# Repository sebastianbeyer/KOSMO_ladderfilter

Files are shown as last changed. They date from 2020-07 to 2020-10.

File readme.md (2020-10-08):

A Kosmo version of the [Kassutronics transistor ladder filter](https://kassu2000.blogspot.com/2018/07/transistor-ladder-filter.html).

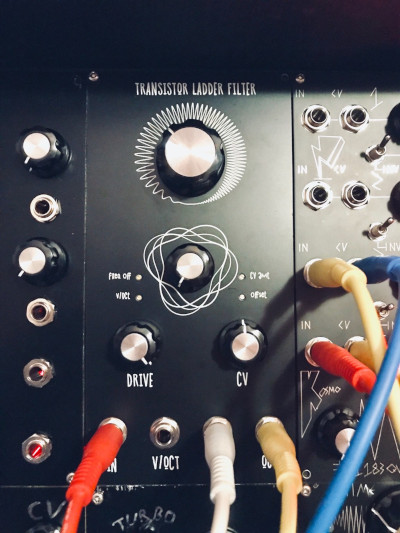
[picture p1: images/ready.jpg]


Find the documentation **and BOM** here: (https://github.com/kassu/kassutronics/tree/master/documentation/Transistor%20Ladder%20Filter)

You need to match the transistors, which is a bit boring. Those that I got where
already pretty close (within the recommended 2mV limit), but some outliers, so
maaaybe you could just try without matching.

# How to make the PCBs

Go download the latest gerber files [here](https://github.com/sebastianbeyer/KOSMO_ladderfilter/releases/latest).
Then send them to your favorite PCB Manufacturer (I use jlcpcb). Make sure you
check "Specify a location" at "Remove Order Number" for the panel.

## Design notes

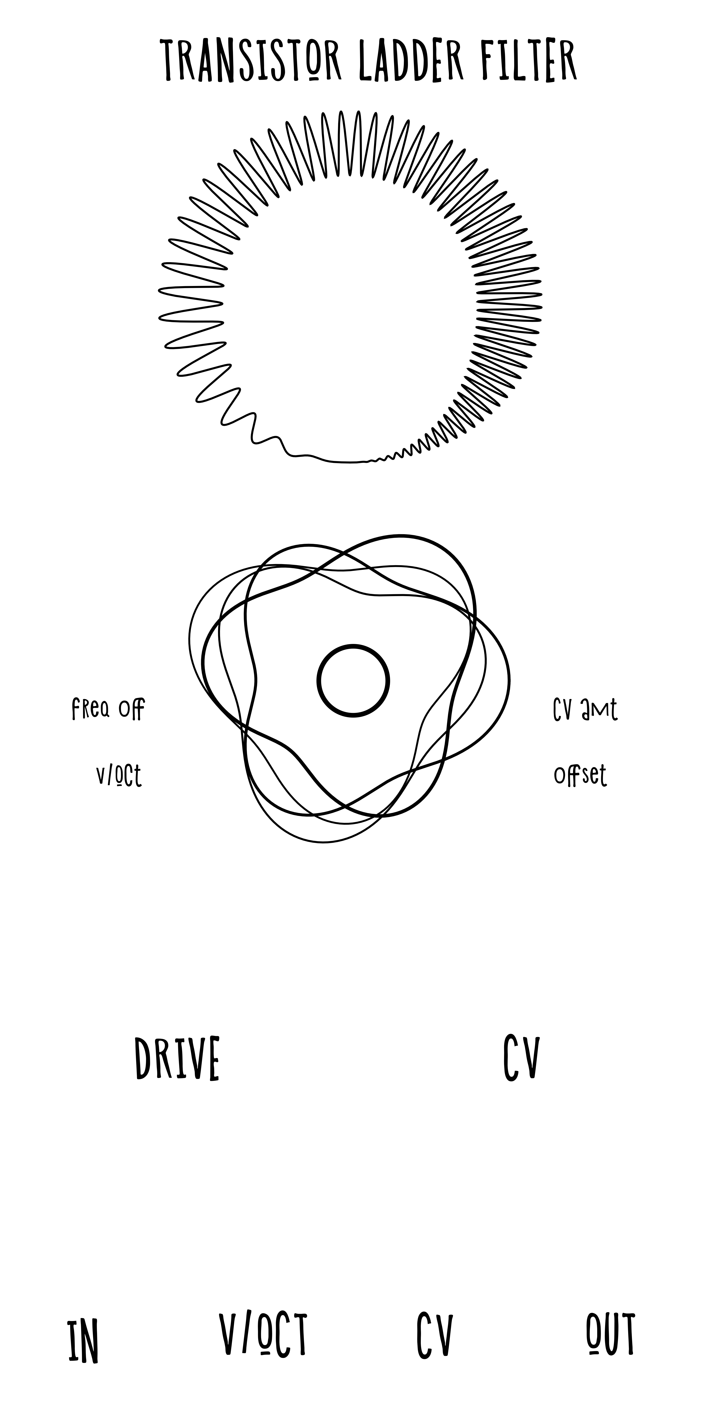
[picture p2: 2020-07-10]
panel/svg/panel_silkscreen.png

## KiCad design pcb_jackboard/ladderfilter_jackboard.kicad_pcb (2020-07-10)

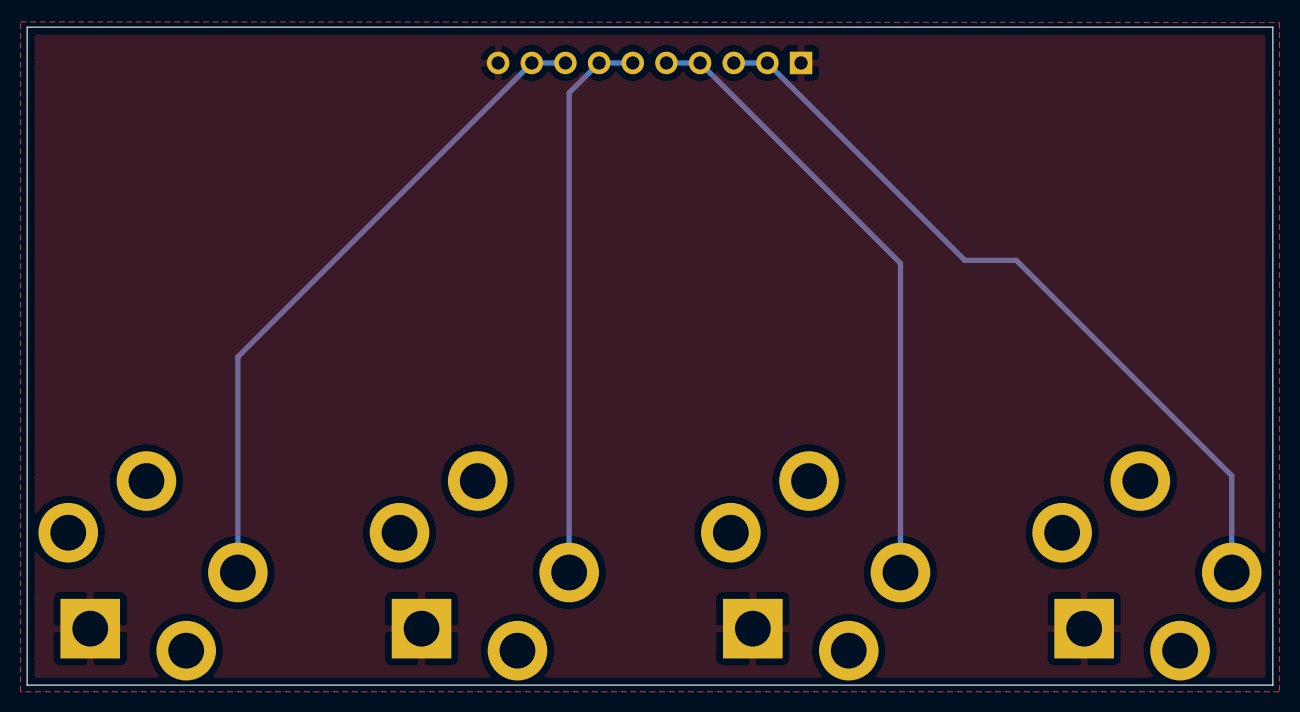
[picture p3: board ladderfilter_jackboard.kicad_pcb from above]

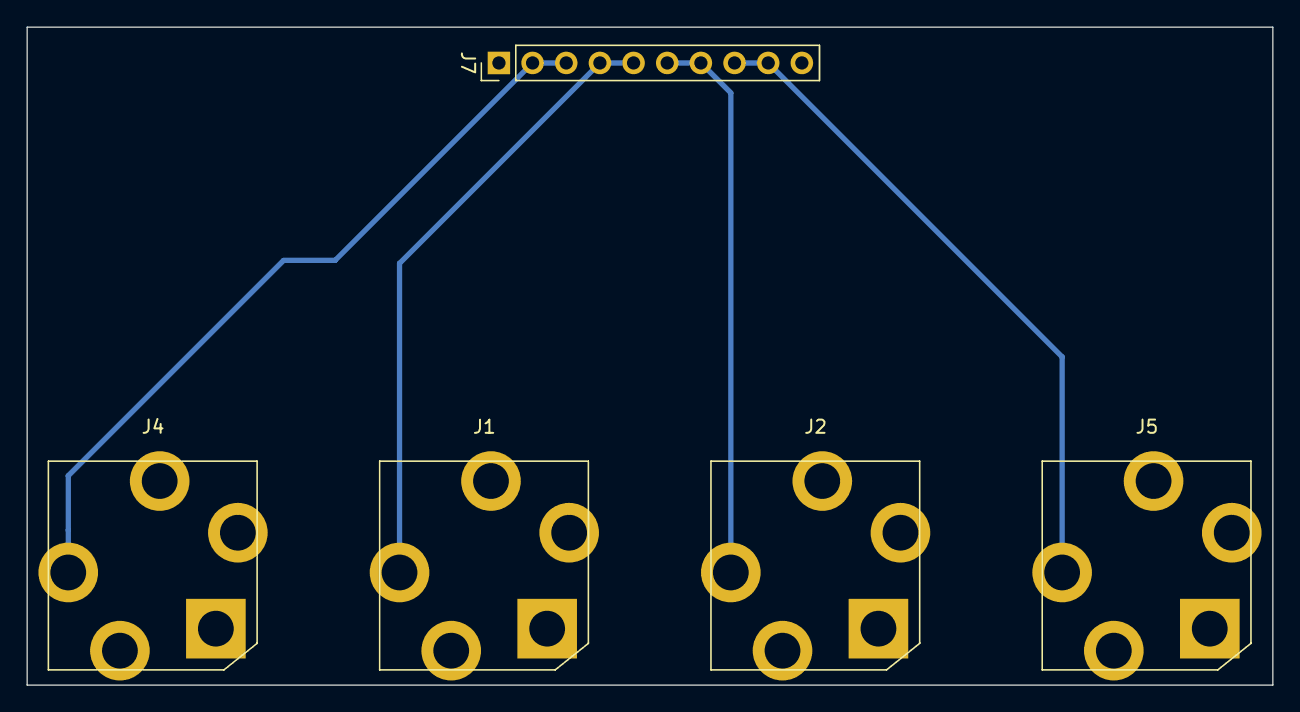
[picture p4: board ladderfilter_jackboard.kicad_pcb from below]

Board: 2 copper layers, 94.0 x 49.7 mm, 5 parts (5 on the bottom side), 5 nets.

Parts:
J1: V/oct in; Jack_6.35mm_PJ_629HAN
J2: CV in; Jack_6.35mm_PJ_629HAN
J4: Audio In; Jack_6.35mm_PJ_629HAN
J5: Audio Out; Jack_6.35mm_PJ_629HAN
J7: header DB; PinHeader_1x10_P2.54mm_Vertical

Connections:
DB_AUDIO_IN: J4.T, J7.2, J7.3
DB_AUDIO_OUT: J5.T, J7.8, J7.9
DB_CV: J2.T, J7.6, J7.7
DB_VOCT: J1.T, J7.4, J7.5
GND: J1.S, J2.S, J4.S, J5.S, J7.1, J7.10

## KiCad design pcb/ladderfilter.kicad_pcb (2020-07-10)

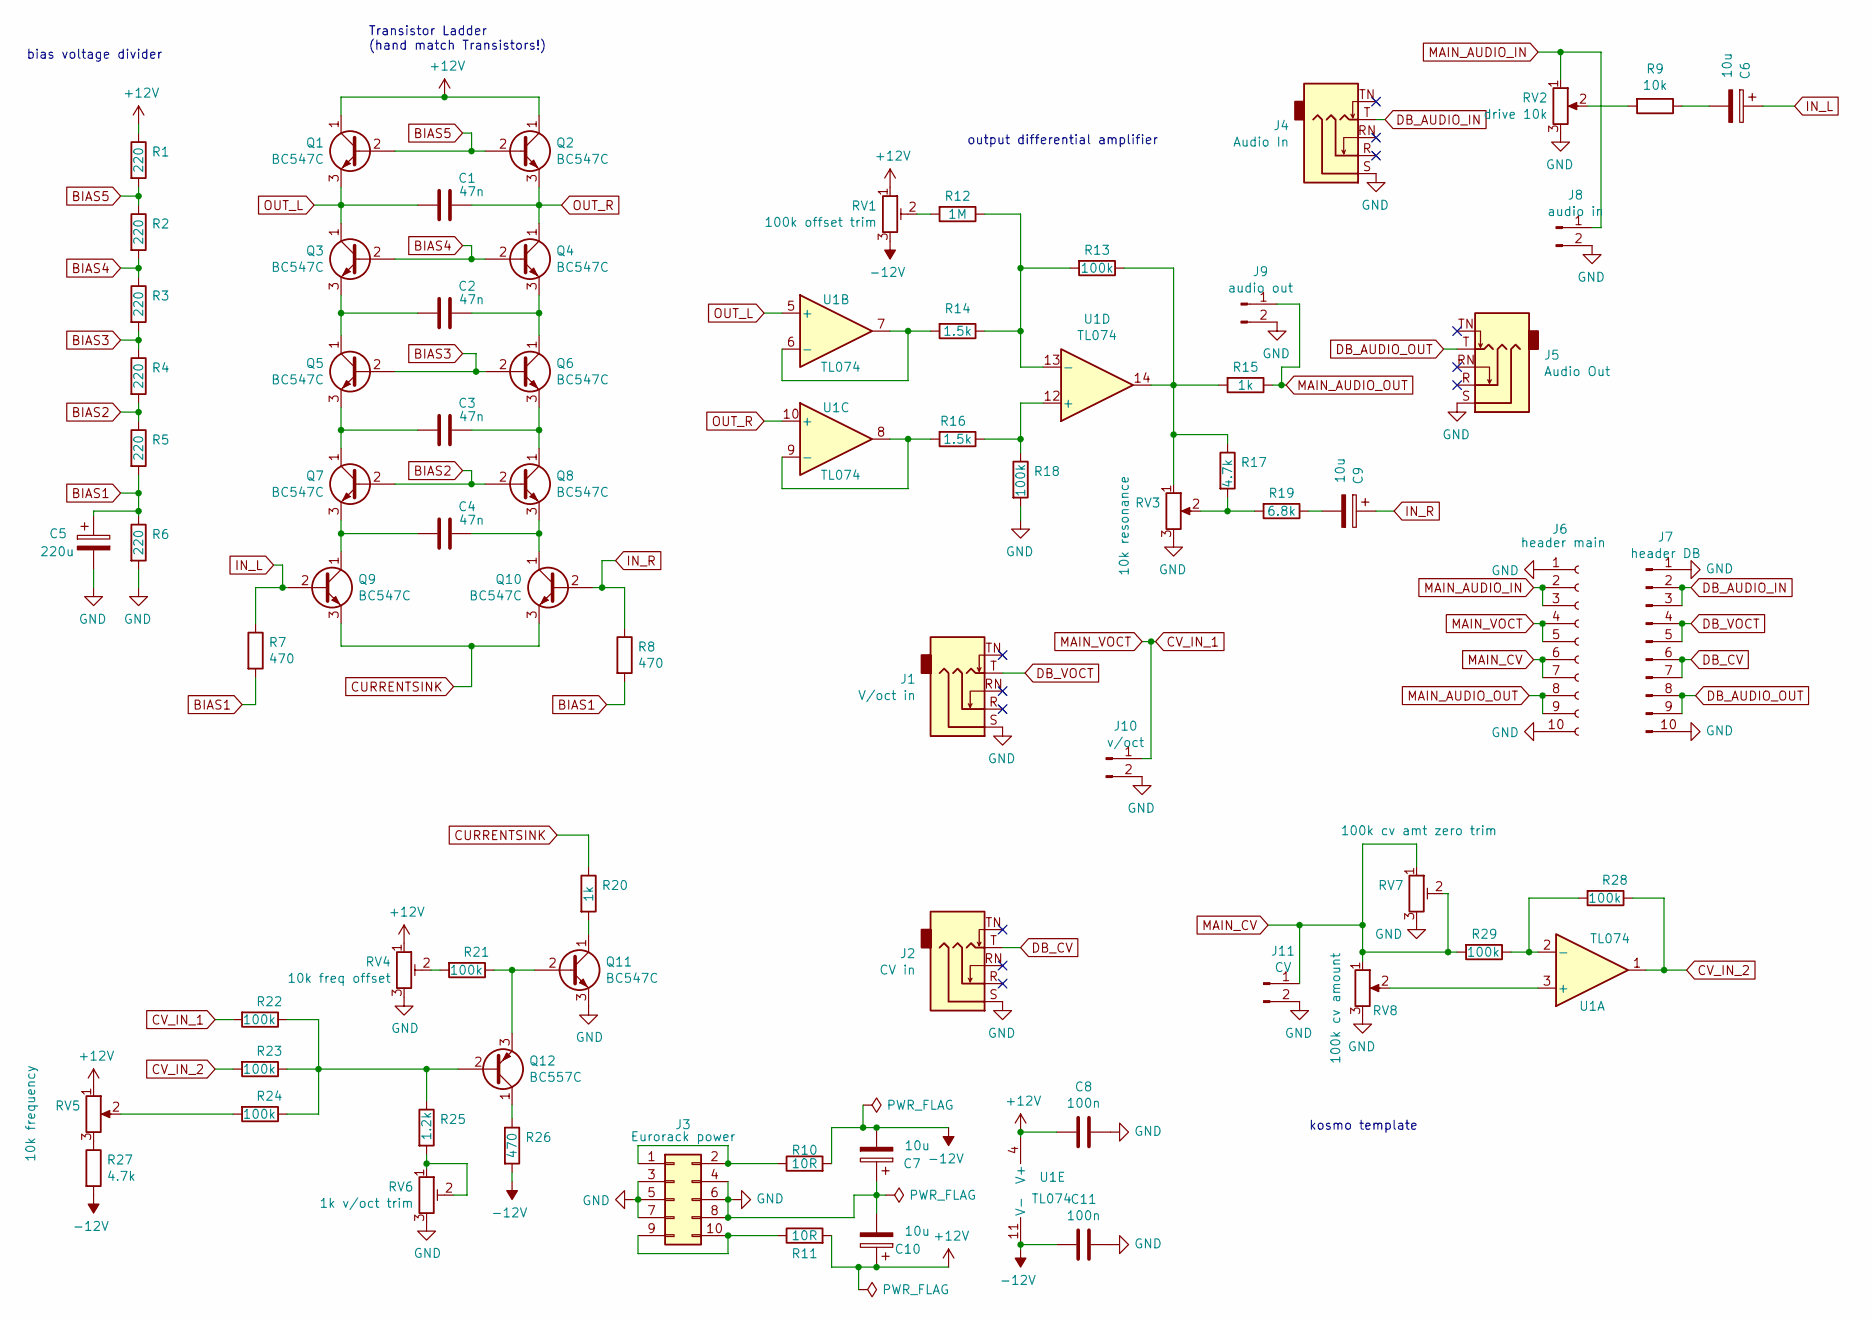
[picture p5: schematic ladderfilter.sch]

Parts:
C1, C2, C3, C4: 47n; C_Rect_L7.2mm_W2.5mm_P5.00mm_FKS2_FKP2_MKS2_MKP2
C5: 220u; CP_Radial_D5.0mm_P2.00mm
C6, C7, C9, C10: 10u; CP_Radial_D5.0mm_P2.00mm
C8, C11: 100n; C_Disc_D4.7mm_W2.5mm_P5.00mm
J1: V/oct in; Jack_6.35mm_PJ_629HAN
J2: CV in; Jack_6.35mm_PJ_629HAN
J3: Eurorack power; Multicomp_MC9A12-1034_2x05_P2.54mm_Vertical
J4: Audio In; Jack_6.35mm_PJ_629HAN
J5: Audio Out; Jack_6.35mm_PJ_629HAN
J6: header main; PinSocket_1x10_P2.54mm_Vertical
J7: header DB; PinHeader_1x10_P2.54mm_Vertical
J8: audio in; Molex_KK-254_AE-6410-02A_1x02_P2.54mm_Vertical
J9: audio out; Molex_KK-254_AE-6410-02A_1x02_P2.54mm_Vertical
J10: v/oct; Molex_KK-254_AE-6410-02A_1x02_P2.54mm_Vertical
J11: CV; Molex_KK-254_AE-6410-02A_1x02_P2.54mm_Vertical
Q1, Q2, Q3, Q4, Q5, Q6, Q7, Q8, Q9, Q10, Q11: BC547C; TO-92_Inline_Wide
Q12: BC557C; TO-92_Inline_Wide
R1, R2, R3, R4, R5, R6: 220; R_Axial_DIN0207_L6.3mm_D2.5mm_P7.62mm_Horizontal_silkvalue
R7, R8, R26: 470; R_Axial_DIN0207_L6.3mm_D2.5mm_P7.62mm_Horizontal_silkvalue
R9: 10k; R_Axial_DIN0207_L6.3mm_D2.5mm_P7.62mm_Horizontal_silkvalue
R10, R11: 10R; R_Axial_DIN0207_L6.3mm_D2.5mm_P7.62mm_Horizontal_silkvalue
R12: 1M; R_Axial_DIN0207_L6.3mm_D2.5mm_P7.62mm_Horizontal_silkvalue
R13, R18, R21, R22, R23, R24, R28, R29: 100k; R_Axial_DIN0207_L6.3mm_D2.5mm_P7.62mm_Horizontal_silkvalue
R14, R16: 1.5k; R_Axial_DIN0207_L6.3mm_D2.5mm_P7.62mm_Horizontal_silkvalue
R15, R20: 1k; R_Axial_DIN0207_L6.3mm_D2.5mm_P7.62mm_Horizontal_silkvalue
R17, R27: 4.7k; R_Axial_DIN0207_L6.3mm_D2.5mm_P7.62mm_Horizontal_silkvalue
R19: 6.8k; R_Axial_DIN0207_L6.3mm_D2.5mm_P7.62mm_Horizontal_silkvalue
R25: 1.2k; R_Axial_DIN0207_L6.3mm_D2.5mm_P7.62mm_Horizontal_silkvalue
RV1: 100k offset trim; Potentiometer_Bourns_3296W_Vertical
RV2: drive 10k; Potentiometer_Alps_RK09K_Single_Vertical
RV3: 10k resonance; Potentiometer_Alps_RK09K_Single_Vertical
RV4: 10k freq offset; Potentiometer_Bourns_3296W_Vertical
RV5: 10k frequency; Potentiometer_Alps_RK09K_Single_Vertical
RV6: 1k v/oct trim; Potentiometer_Bourns_3296W_Vertical
RV7: 100k cv amt zero trim; Potentiometer_Bourns_3296W_Vertical
RV8: 100k cv amount; Potentiometer_Alps_RK09K_Single_Vertical
U1: TL074; DIP-14_W7.62mm_Socket_LongPads

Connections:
+12V: C8.2, C10.1, Q1.1 (C), Q2.1 (C), R1.1, R11.2, RV1.1, RV4.1, RV5.1, U1.4 (V+)
-12V: C7.2, C11.2, R10.2, R26.2, R27.2, RV1.3, U1.11 (V-)
BIAS1: C5.1, R5.2, R6.1, R7.2, R8.2
BIAS2: Q7.2 (B), Q8.2 (B), R4.2, R5.1
BIAS3: Q5.2 (B), Q6.2 (B), R3.2, R4.1
BIAS4: Q3.2 (B), Q4.2 (B), R2.2, R3.1
BIAS5: Q1.2 (B), Q2.2 (B), R1.2, R2.1
CURRENTSINK: Q9.3 (E), Q10.3 (E), R20.1
CV_IN_1: J6.4, J6.5, J10.1, R22.2
CV_IN_2: R23.2, R28.1, U1.1
GND: C5.2, C7.1, C8.1, C10.2, C11.1, J1.S, J2.S, J3.3, J3.4, J3.5, J3.6, J3.7, J3.8, J4.S, J5.S, J6.1, J6.10, J7.1, J7.10, J8.2, J9.2, J10.2, J11.2, Q11.3 (E), R6.2, R18.2, RV2.3, RV3.3, RV4.3, RV6.3, RV7.3, RV8.3
IN_L: C6.1, Q9.2 (B), R7.1
IN_R: C9.1, Q10.2 (B), R8.1
MAIN_AUDIO_IN: J6.2, J6.3, J8.1, RV2.1
MAIN_AUDIO_OUT: J6.8, J6.9, J9.1, R15.1
MAIN_CV: J6.6, J6.7, J11.1, R29.2, RV7.1, RV7.2, RV8.1
unnamed: C2.1, Q4.3 (E), Q6.1 (C)
unnamed: C2.2, Q3.3 (E), Q5.1 (C)
unnamed: C3.1, Q6.3 (E), Q8.1 (C)
unnamed: C3.2, Q5.3 (E), Q7.1 (C)
unnamed: C4.1, Q8.3 (E), Q10.1 (C)
unnamed: C4.2, Q7.3 (E), Q9.1 (C)
unnamed: C6.2, R9.1
unnamed: C9.2, R19.1
unnamed: J1.T, J7.4, J7.5
unnamed: J2.T, J7.6, J7.7
unnamed: J3.1, J3.2, R10.1
unnamed: J3.9, J3.10, R11.1
unnamed: J4.T, J7.2, J7.3
unnamed: J5.T, J7.8, J7.9
unnamed: Q11.1 (C), R20.2
unnamed: Q11.2 (B), Q12.3 (E), R21.1
unnamed: Q12.1 (C), R26.1
unnamed: Q12.2 (B), R22.1, R23.1, R24.1, R25.1
unnamed: R9.2, RV2.2
unnamed: R12.1, R13.2, R14.1, U1.13 (-)
unnamed: R12.2, RV1.2
unnamed: R13.1, R15.2, R17.1, RV3.1, U1.14
unnamed: R14.2, U1.6 (-), U1.7
unnamed: R16.1, R18.1, U1.12 (+)
unnamed: R16.2, U1.8, U1.9 (-)
unnamed: R17.2, R19.2, RV3.2
unnamed: R21.2, RV4.2
unnamed: R24.2, RV5.2
unnamed: R25.2, RV6.1, RV6.2
unnamed: R27.1, RV5.3
unnamed: R28.2, R29.1, U1.2 (-)
unnamed: RV8.2, U1.3 (+)
OUT_L: C1.2, Q1.3 (E), Q3.1 (C), U1.5 (+)
OUT_R: C1.1, Q2.3 (E), Q4.1 (C), U1.10 (+)

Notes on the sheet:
kosmo template
bias voltage divider
Transistor Ladder (hand match Transistors!)
output differential amplifier

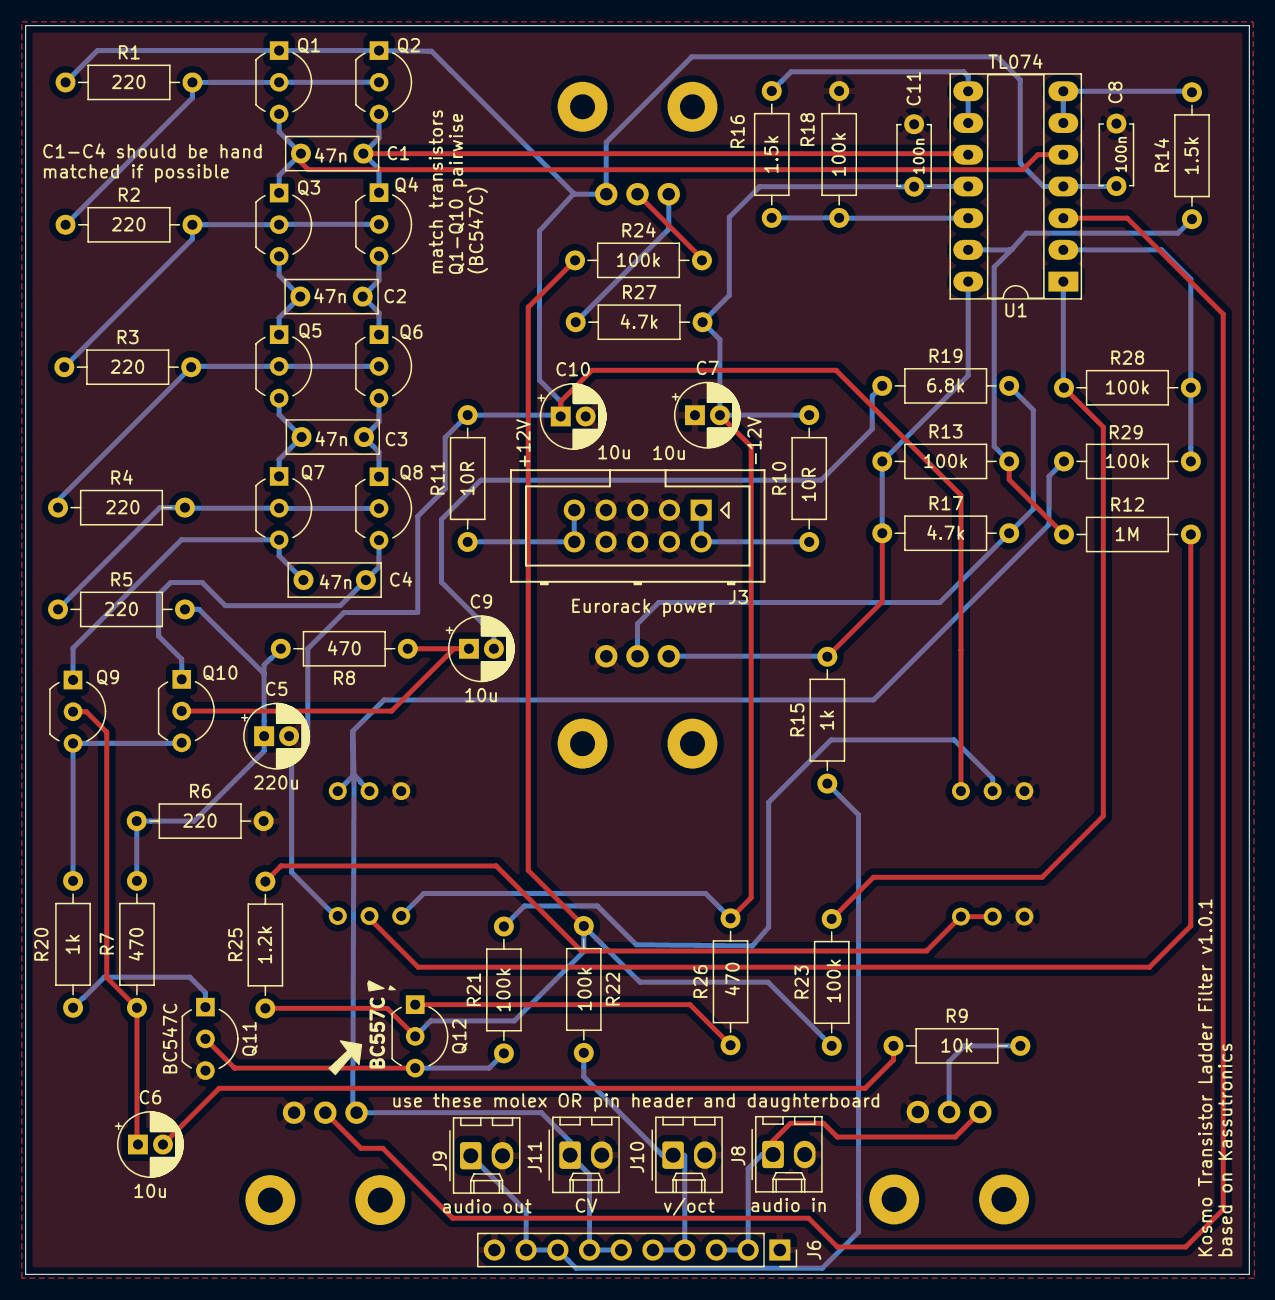
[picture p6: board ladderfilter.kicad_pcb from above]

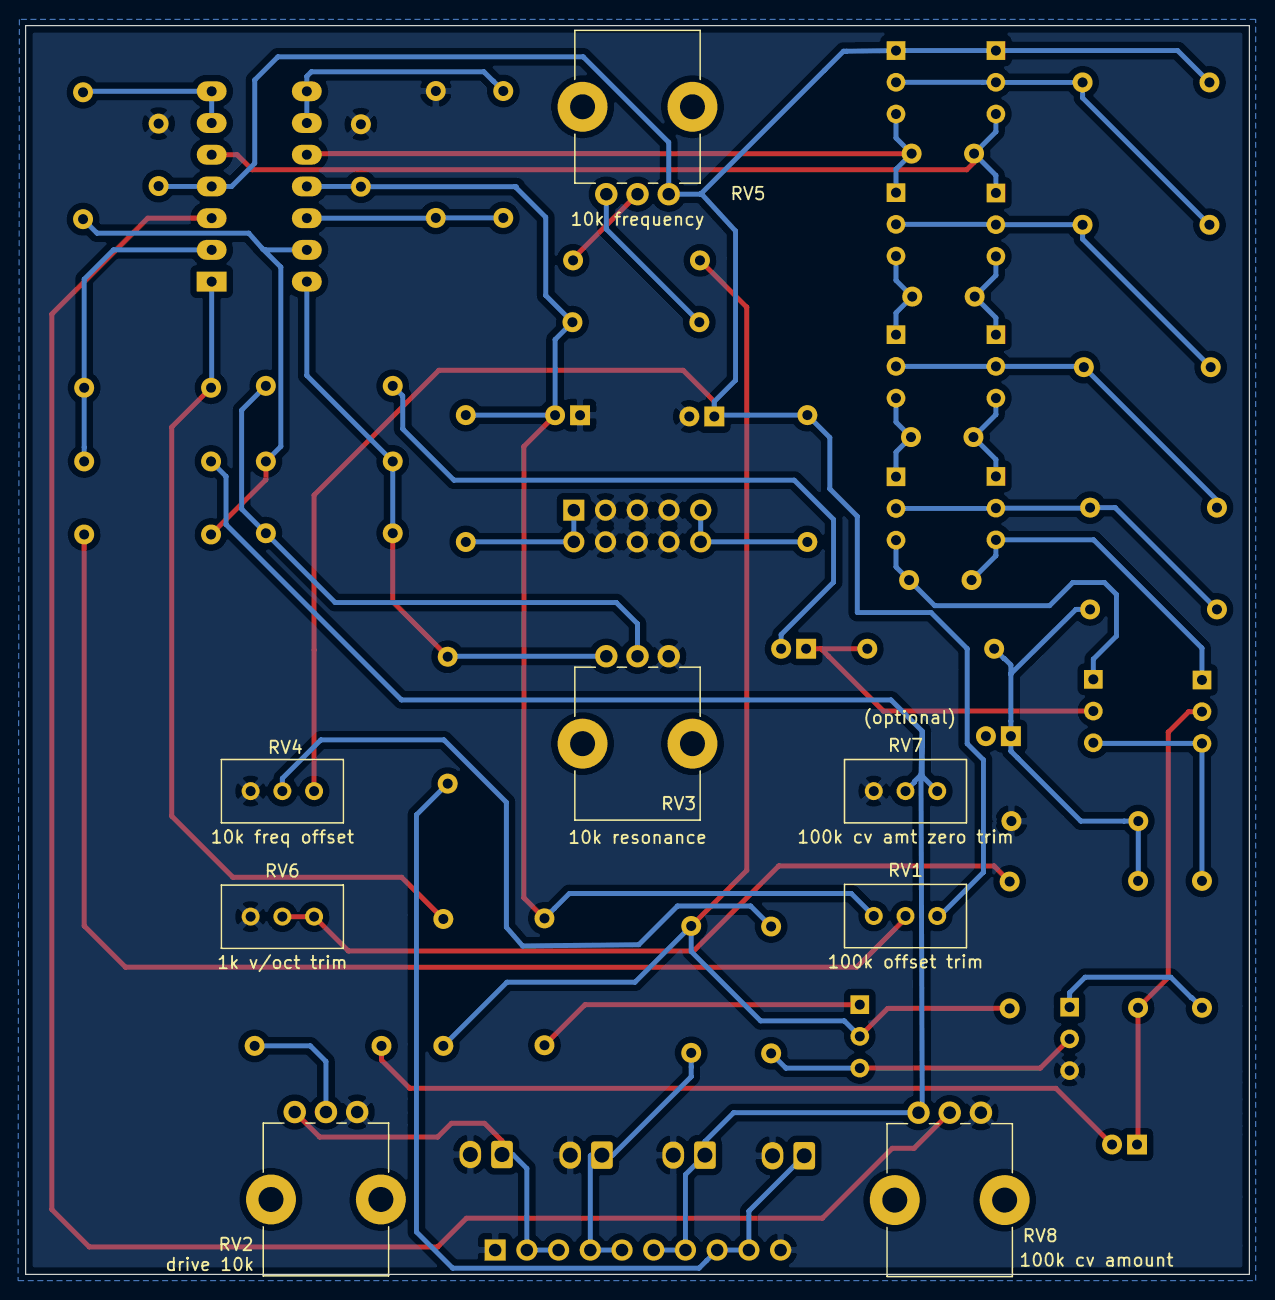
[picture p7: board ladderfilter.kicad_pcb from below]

Board: 2 copper layers, 98.0 x 100.0 mm, 67 parts (8 on the bottom side), 46 nets.
